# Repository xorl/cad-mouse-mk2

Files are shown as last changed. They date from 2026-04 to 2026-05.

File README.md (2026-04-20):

# CAD Mouse MK2

Watch the build video ↓

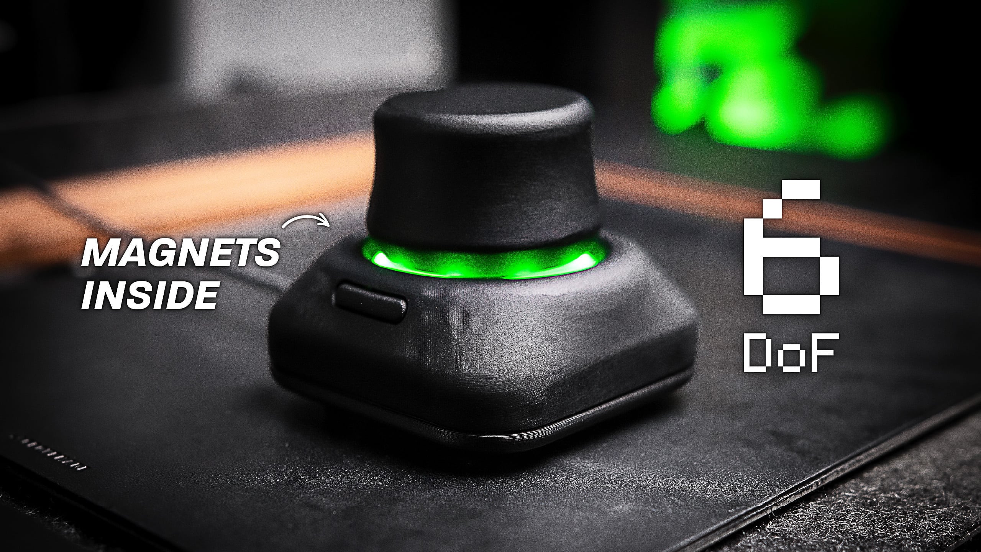
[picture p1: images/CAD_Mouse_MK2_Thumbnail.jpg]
[](https://youtu.be/62xlzGs8LXA)

This is the second iteration of my DIY CAD Mouse, rebuilt to behave like a real 6DoF controller. There are still some motion processing issues, but it's much better than the previous version. It uses a custom PCB with three magnetic sensors, a 3D printed spring, and a redesigned enclosure that is smaller and easier to build.

  Build instructions → [Instructables](https://www.instructables.com/CAD-Mouse-MK2-a-6DoF-Space-Mouse-Using-Magnets)

<sub>⚠️ There have been several comments raising concerns about the longevity of the PETG spring. If it does not last as expected, a revision of the knob design will be needed.</sub>

[][cc-by-nc-sa]

[][cc-by-nc-sa]

[cc-by-nc-sa]: http://creativecommons.org/licenses/by-nc-sa/4.0/
[cc-by-nc-sa-image]: https://licensebuttons.net/l/by-nc-sa/4.0/88x31.png
[cc-by-nc-sa-shield]: https://img.shields.io/badge/License-CC%20BY--NC--SA%204.0-lightgrey.svg

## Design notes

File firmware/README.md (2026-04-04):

You can customize several variables to tune gains, smoothing, and deadzones for all six axes.
Most of these settings are defined in [`Config.h`](include/Config.h) and are the main place to adjust the overall feel of the device.

```cpp
// Gains and sign fixes
const float GAIN_T[3] = {28.0, 28.0, 24.0};
const float GAIN_R[3] = {18.0, 18.0, 20.0};
const int SIGN_AXIS[6] = {-1, +1, -1, +1, +1, +1};

// Dead zones
const float DEAD_T = 16.0;
const float DEAD_R = 20.0;

// Smoothing
const float SMOOTH_TAU_S = 0.08;
```

⚠️ Refer to the video at [6:23](https://youtu.be/62xlzGs8LXA?si=ld2shDCaTxOLIGB8&t=383) for a demo of driver support. Related settings can be found commented in[`platformio.ini`](../platformio.ini).

⚠️ As mentioned in the video, the motion processing still needs work and may eventually be replaced entirely. This is beyond me for now, so contributions and improvements are welcome.

There is bleed between the axis due to the way each of them is calculated independently. This implementation also assumes the readings from the sensors are linear, which is not true.

If you want to experiment with different motion processing approaches, you can modify the [`MotionController`](src/controllers/MotionController.cpp). The current implementation is as follows:

**Sensor layout:**
- `mag1` = bottom
- `mag2` = top left
- `mag3` = top right

```
Tx = (mag1x + mag2x + mag3x) / 3
Ty = (mag1y + mag2y + mag3y) / 3
Tz = (mag1z + mag2z + mag3z) / 3

Rx = sqrt(3) * (mag2z + mag3z - 2 * mag1z) / 3
Ry = mag3z - mag2z
Rz = sum_i (posXi * magYi - posYi * magXi)
```
- `Tx`, `Ty`, `Tz`: average of all three sensors
- `Ry`: left-right z difference across the top edge
- `Rx`: top pair versus bottom, scaled for the triangle geometry
- `Rz`: twist estimate from the x/y sensor positions

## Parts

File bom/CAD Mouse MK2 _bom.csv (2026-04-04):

Qty | Part | Link
1 | Seeed Studio XIAO RP2040 | https://geni.us/9SqAMi
1 | Assembled Sensor Board with MCU Adapter | https://bit.ly/48rovz3
16 | M3 x 4 Heat-Set Inserts | https://geni.us/s0GG2
10 | M3 x 16 Hexagon Socket Head Cap Screw | https://geni.us/ncMxqyo
5 | M3 x 12 Hexagon Socket Head Cap Screw | https://geni.us/ncMxqyo
1 | M2 x 4 Hexagon Socket Head Cap Screw | https://geni.us/ncMxqyo
6 | 6mm x 3mm Neodymium Magnets | https://geni.us/JU58
4 | Rubber Bumper Feet | https://geni.us/vBw7v

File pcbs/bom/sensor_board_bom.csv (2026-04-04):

Reference Designators | Quantity | Description | Package | Value | Digikey
C1, C2 | 2 | 1 µF ±20% 10V Ceramic Capacitor X7R 1206 (3216 Metric) | CAPC3216X135 | 1uF | 4713-GMC31X7R105M10NTCT-ND
C3, C4, C5, C6, C7, C8, C9, C10, C11, C12, C13, C14, C15, C16, C17 | 15 | 0.1 µF ±20% 16V Ceramic Capacitor X7R 0805 (2012 Metric) | CAPC2012X110 | 100nF | 399-C0805C104K5RACTUCT-ND
C18 | 1 | 22 µF ±20% 25V Ceramic Capacitor X5R 1206 (3216 Metric) | CAPC3216X135 | 22uF | 587-3246-1-ND
D1, D2, D3, D4, D5, D6, D7, D8 | 8 | Addressable Lighting - LED Red, Green, Blue (RGB) 4.00mm L x 2.00mm W | LED_SK6812_SIDE-A | SK6812_SIDE-A | 3147-T4203GRB-12C-61013TU1930CT-ND
J1, J2 | 2 | 6 Position Header Connector 0.079" (2.00mm) Through Hole Gold | CONN3X2_NPPN032AFCN-RC_SUL | NPPN032AFCN-RCCONN3X2_NPPN032AFCN-RC_SUL | S5750-03-ND
MAG1, MAG2, MAG3 | 3 | Hall Effect Sensor Axis PG-TSOP6-6-8 (TLI493D-A2B6) | SOP95P280X110-6N-V | TLI493D-A2B6 | TLI493DA2B6HTSA1CT-ND
R1, R2 | 2 | 10 kOhms ±1% 0.125W, 1/8W Chip Resistor 0805 (2012 Metric) Automotive AEC-Q200 Thick Film | RESC2012X65 | 10K | RMCF0805FT10K0CT-ND
RN1 | 1 | 10k Ohm ±5% 62.5mW Power Per Element Isolated 4 Resistor Network/Array ±200ppm/°C 1206 (3216 Metric), Convex, Long Side Terminals | RESCAF80P320X160X60-8N | CAY16-103J4LF | CAY16-103J4LFCT-ND
S1, S2 | 2 | Tactile Switch SPST-NO Side Actuated Surface Mount, Right Angle | SW_TS32-7-35-BK-160-RA-SMT-TR | TS32-7-35-BK-160-RA-SMT-TR | 2223-TS32-7-35-BK-160-RA-SMT-TRCT-ND
U1, U2, U3, U4 | 4 | Power Switch/Driver 1:1 N/P-Channel 1A TSOT-25 | SOT95P280X100-5N | AP22816BKEWT-7 | 31-AP22816AKEWT-7CT-ND
U5 | 1 | Buffer, Non-Inverting 1 Element 1 Bit per Element 3-State Output SOT-23-5 | SOT95P280X145-5N | SN74AHCT1G125DBVR | 296-4708-1-ND
H1, H2 | 2 | Connector Header Through Hole 6 position 0.079" (2.00mm) | CONN3X2_NRPN032PAEN | NRPN032PAEN-RC | S5801-03-ND

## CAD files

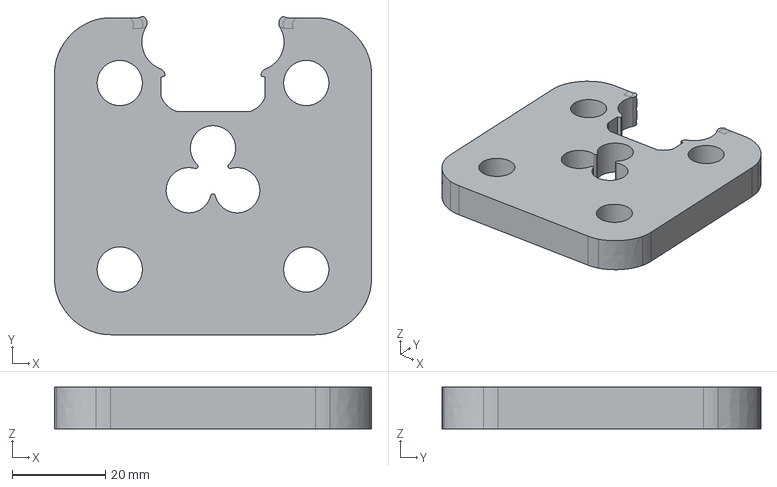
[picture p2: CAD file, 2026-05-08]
enclosure/step/void-fill.step
68.0 x 68.3 x 9.00 mm

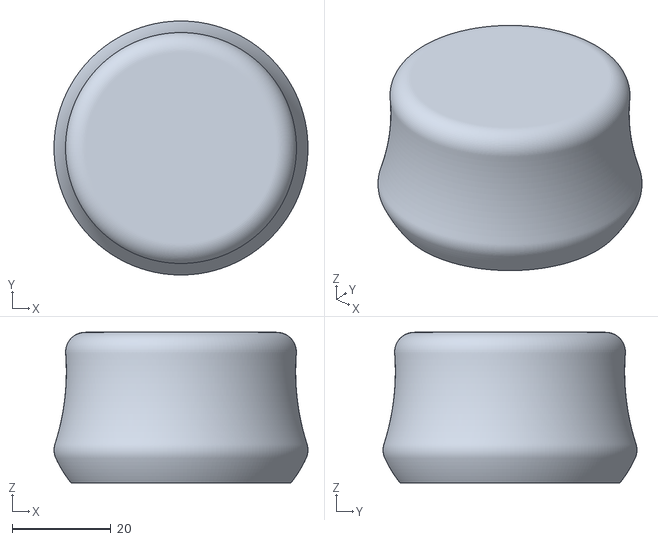
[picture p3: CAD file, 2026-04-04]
enclosure/stl/knob.stl
51.5 x 51.5 x 30.5

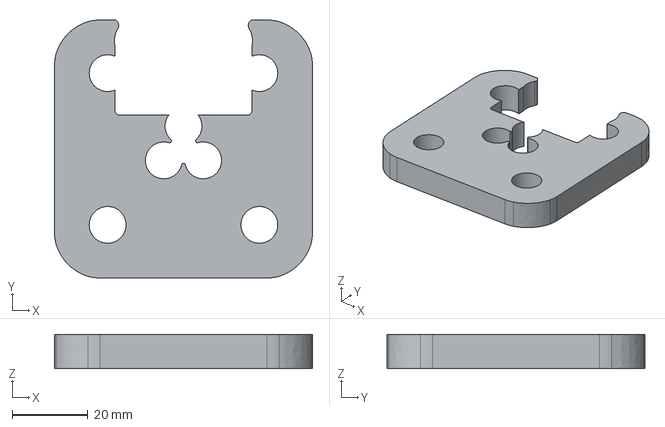
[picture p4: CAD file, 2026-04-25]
enclosure/step/Weight-for-Cad-Mouse.step
68.0 x 68.0 x 9.00 mm

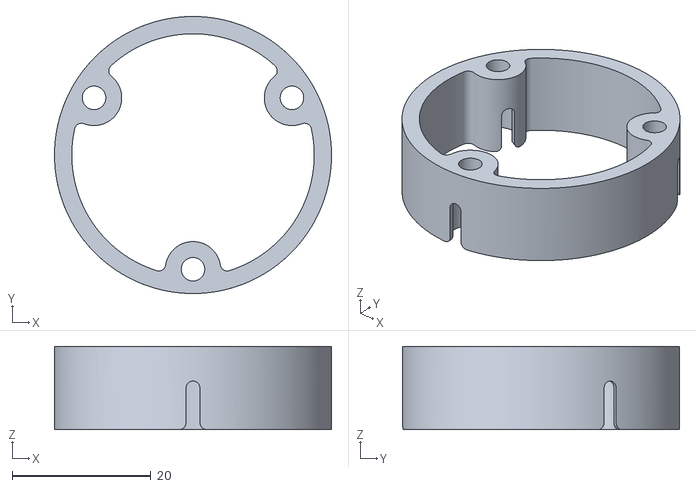
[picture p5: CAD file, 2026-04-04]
enclosure/stl/magnet_holder.stl
40.0 x 40.0 x 12.0

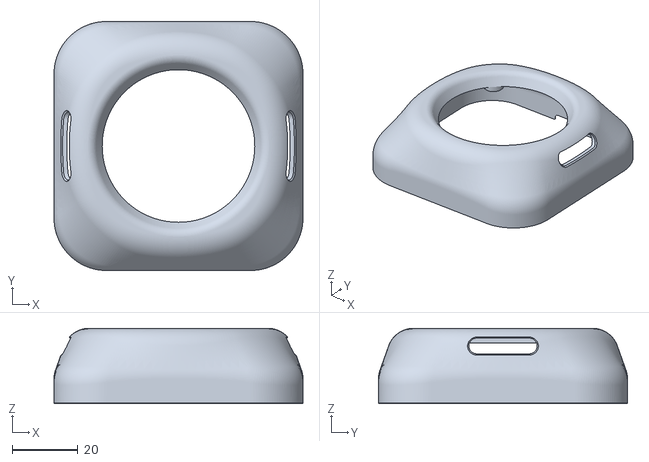
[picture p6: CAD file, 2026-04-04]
enclosure/stl/base_shell_top.stl
76.0 x 76.0 x 23.0

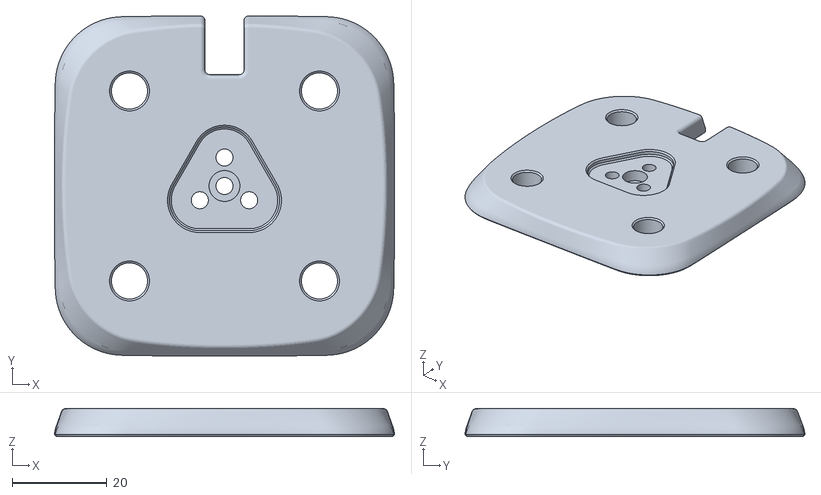
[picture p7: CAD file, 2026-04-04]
enclosure/stl/base_separator.stl
71.6 x 71.6 x 5.90

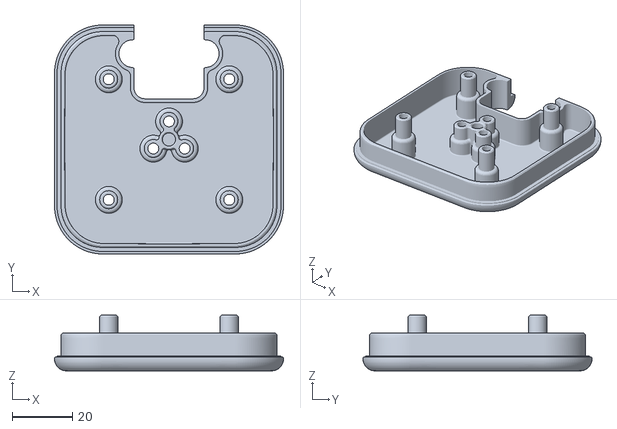
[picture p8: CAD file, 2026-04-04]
enclosure/stl/base_shell_bottom.stl
76.0 x 76.0 x 18.5

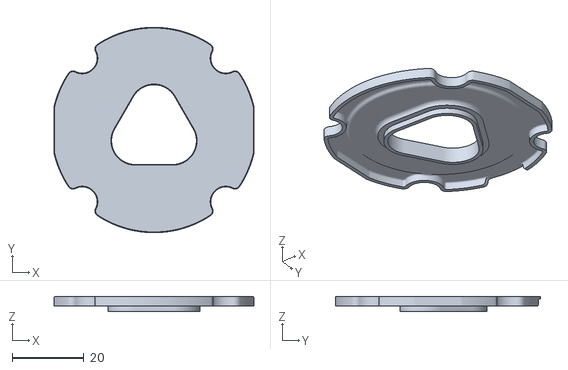
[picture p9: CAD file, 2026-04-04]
enclosure/stl/diffuser.stl
55.7 x 57.2 x 4.24

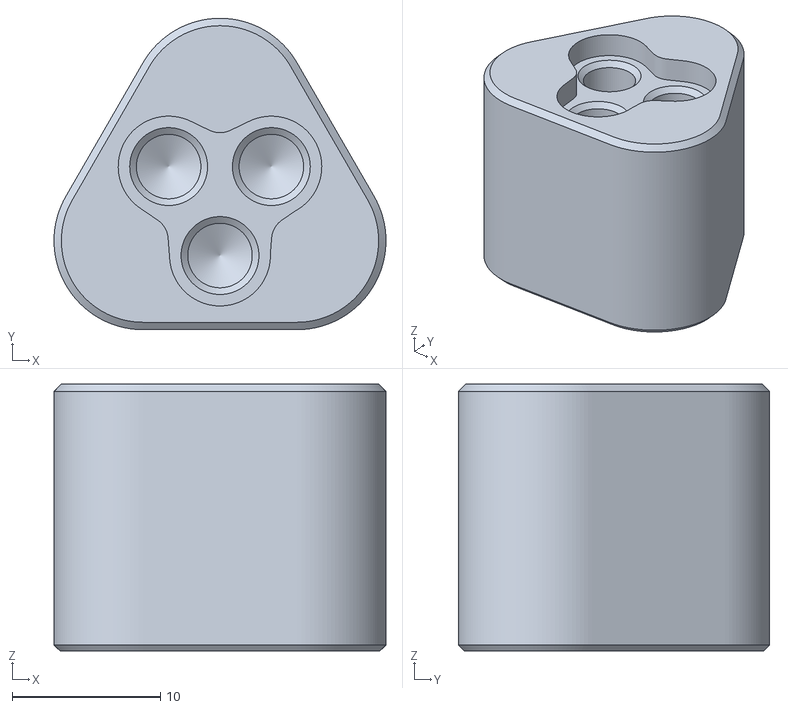
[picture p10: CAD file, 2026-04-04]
enclosure/stl/stem.stl
22.4 x 21.0 x 18.0

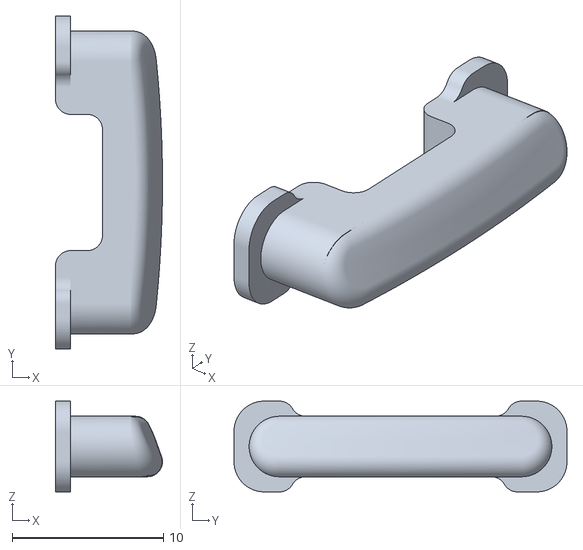
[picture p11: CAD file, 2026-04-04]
enclosure/stl/side_button.stl
7.07 x 22.0 x 6.00

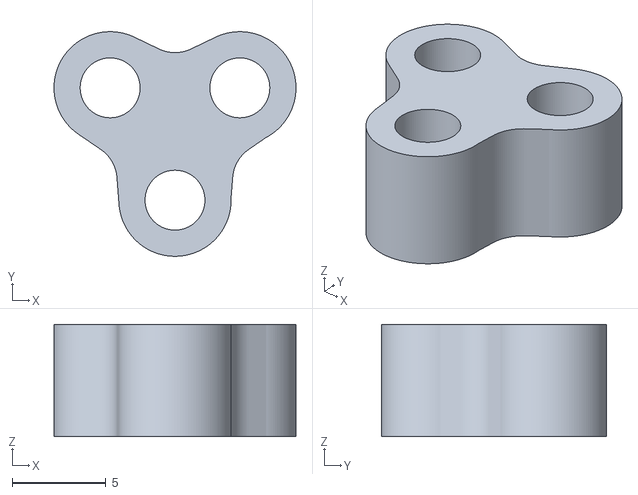
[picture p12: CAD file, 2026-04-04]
enclosure/stl/spring_spacer.stl
12.9 x 12.0 x 6.00

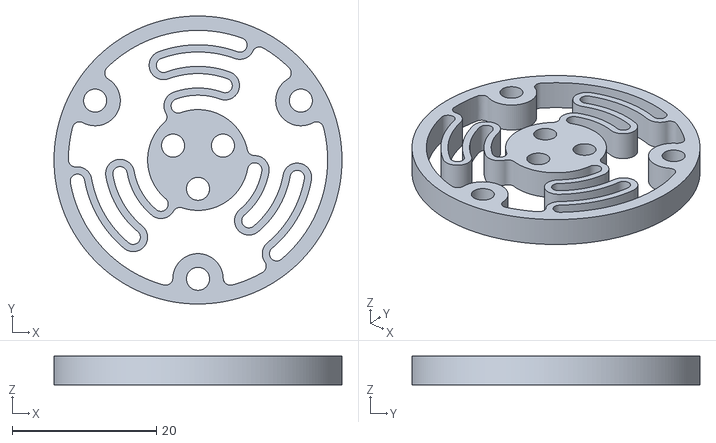
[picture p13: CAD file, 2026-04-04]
enclosure/stl/spring_1_30.stl
40.0 x 40.0 x 4.00

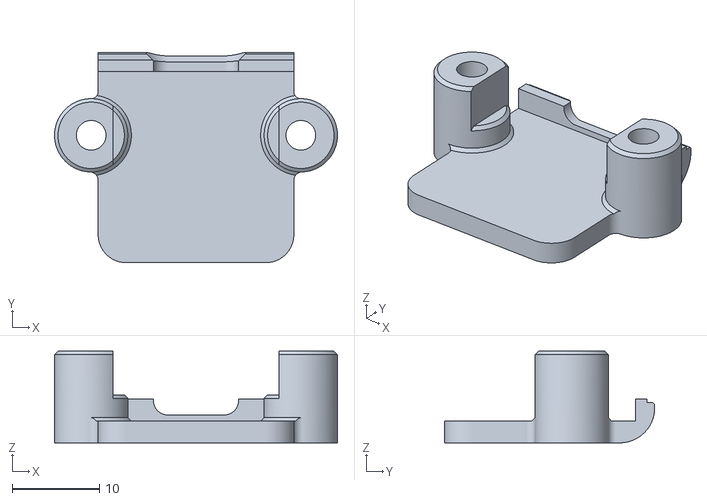
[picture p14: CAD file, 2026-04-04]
enclosure/stl/base_mcu_cover.stl
32.4 x 24.1 x 10.5

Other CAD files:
enclosure/fusion/Spring (parametric).f3d
enclosure/step/void-fill.stl

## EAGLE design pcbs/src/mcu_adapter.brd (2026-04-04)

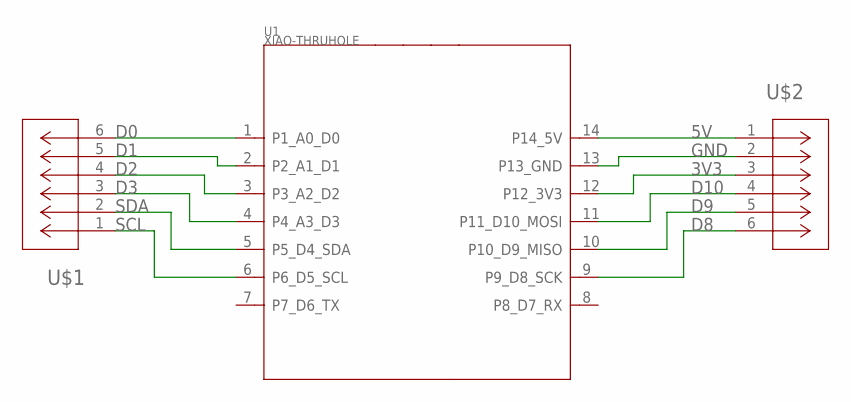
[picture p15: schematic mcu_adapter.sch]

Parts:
U1: XIAO-THRUHOLE; XIAO-GENERIC-THRUHOLE-MODULE14P-2.54-21X17.8MM
U$1, U$2: NRPN032PAEN-RC; CONN3X2_NRPN032PAEN-RC

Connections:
3V3: U1.12 (P12_3V3), U$2.3
5V: U1.14 (P14_5V), U$2.1
D0: U1.1 (P1_A0_D0), U$1.6
D1: U1.2 (P2_A1_D1), U$1.5
D2: U1.3 (P3_A2_D2), U$1.4
D3: U1.4 (P4_A3_D3), U$1.3
D8: U1.9 (P9_D8_SCK), U$2.6
D9: U1.10 (P10_D9_MISO), U$2.5
D10: U1.11 (P11_D10_MOSI), U$2.4
GND: U1.13 (P13_GND), U$2.2
SCL: U1.6 (P6_D5_SCL), U$1.1
SDA: U1.5 (P5_D4_SDA), U$1.2

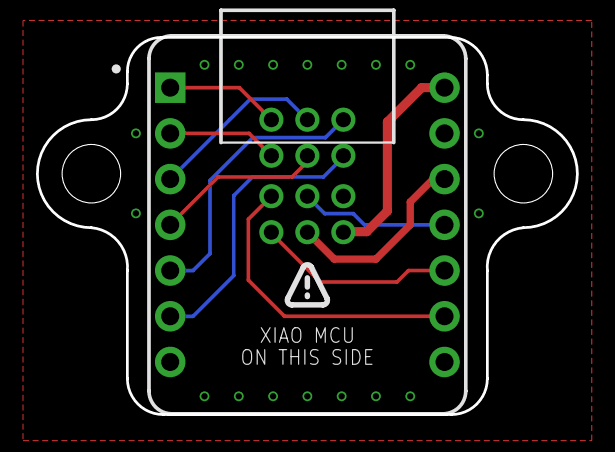
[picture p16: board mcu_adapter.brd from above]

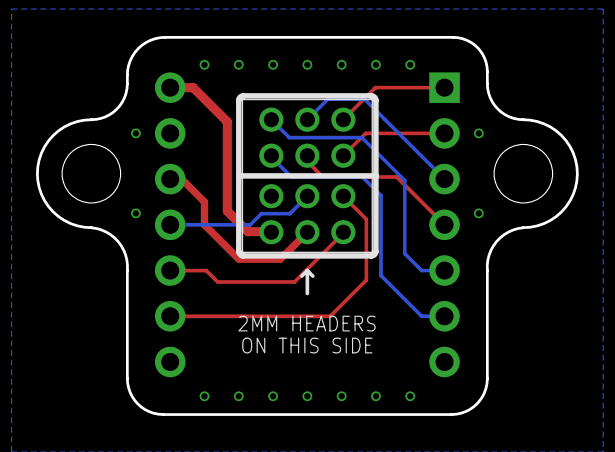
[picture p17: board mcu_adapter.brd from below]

Board: 2 copper layers, 30.0 x 21.0 mm, 3 parts (2 on the bottom side), 12 nets.

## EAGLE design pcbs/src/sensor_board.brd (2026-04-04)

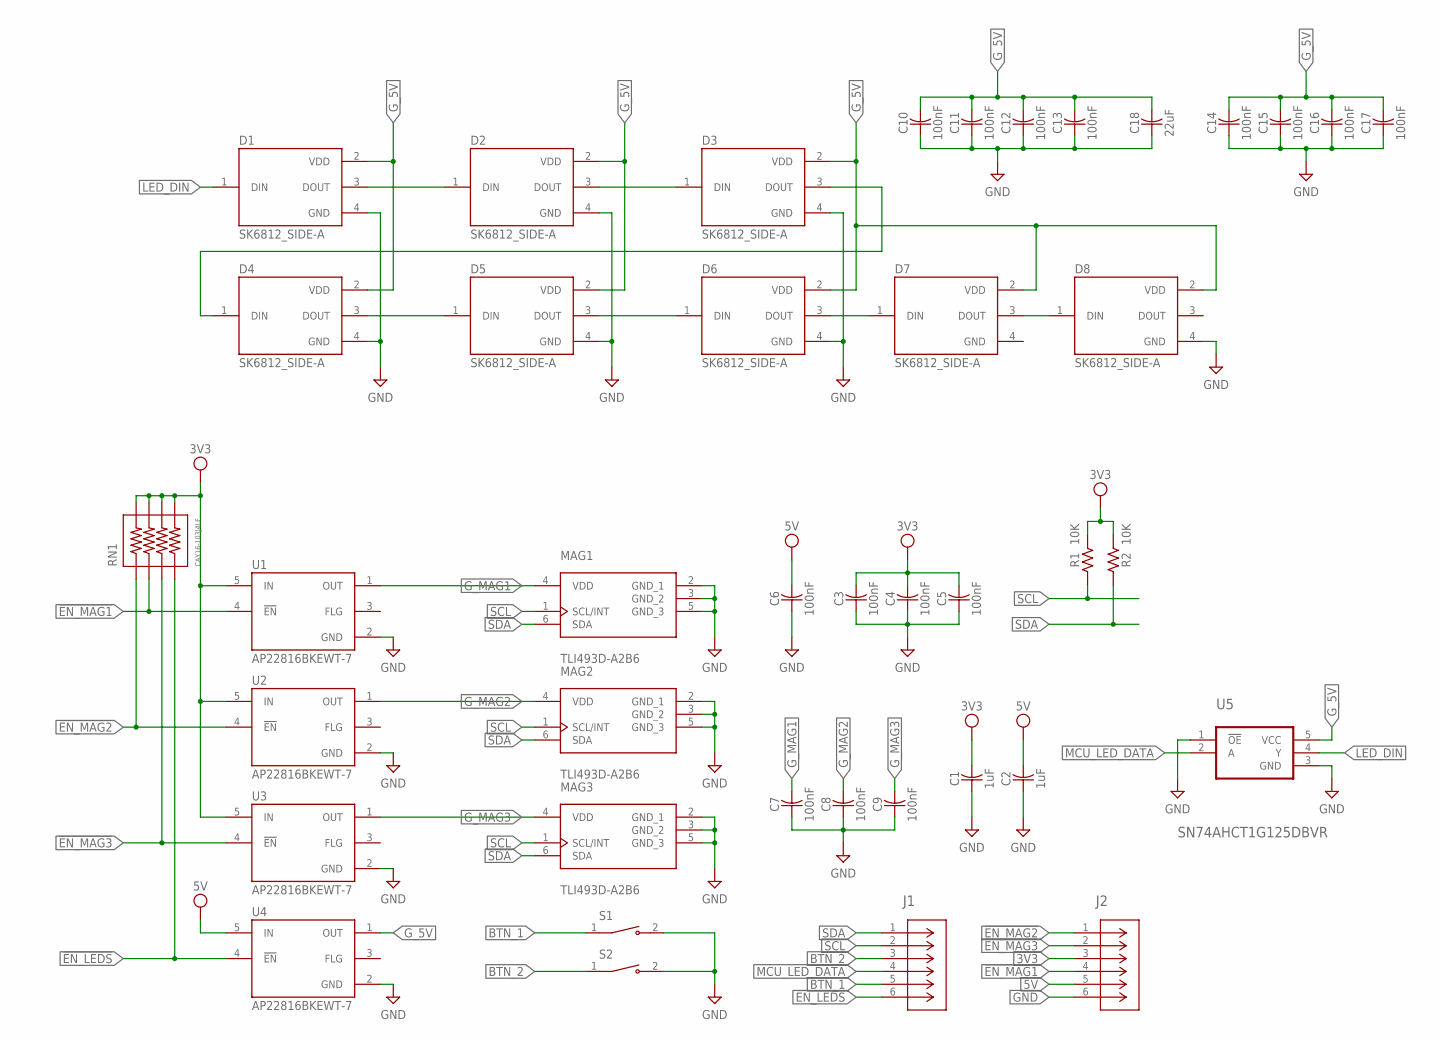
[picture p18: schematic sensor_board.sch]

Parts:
C1, C2: 1uF; CAPC3216X135
C3, C4, C5, C6, C7, C8, C9, C10, C11, C12, C13, C14, C15, C16, C17: 100nF; CAPC2012X110
C18: 22uF; CAPC3216X135
D1, D2, D3, D4, D5, D6, D7, D8: SK6812_SIDE-A; LED_SK6812_SIDE-A
J1, J2: NPPN032AFCN-RCCONN3X2_NPPN032AFCN-RC_SUL; CONN3X2_NPPN032AFCN-RC_SUL
MAG1, MAG2, MAG3: TLI493D-A2B6; SOP95P280X110-6N-V
R1, R2: 10K; RESC2012X65
RN1: CAY16-103J4LF; RESCAF80P320X160X60-8N
S1, S2: TS32-7-35-BK-160-RA-SMT-TR; SW_TS32-7-35-BK-160-RA-SMT-TR
U1, U2, U3, U4: AP22816BKEWT-7; SOT95P280X100-5N
U5: SN74AHCT1G125DBVR; SOT95P280X145-5N

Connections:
3V3: C1.2, C3.2, C4.2, C5.2, J2.3, R1.2, R2.2, RN1.5, RN1.6, RN1.7, RN1.8, U1.5 (IN), U2.5 (IN), U3.5 (IN)
5V: C2.2, C6.2, J2.5, U4.5 (IN)
!EN_LEDS: J1.6, RN1.4, U4.4 (!EN)
!EN_MAG1: J2.4, RN1.2, U1.4 (!EN)
!EN_MAG2: J2.1, RN1.1, U2.4 (!EN)
!EN_MAG3: J2.2, RN1.3, U3.4 (!EN)
BTN_1: J1.5, S1.1
BTN_2: J1.3, S2.1
GND: C1.1, C2.1, C3.1, C4.1, C5.1, C6.1, C7.1, C8.1, C9.1, C10.1, C11.1, C12.1, C13.1, C14.1, C15.1, C16.1, C17.1, C18.1, D1.4 (GND), D2.4 (GND), D3.4 (GND), D4.4 (GND), D5.4 (GND), D6.4 (GND), D7.4 (GND), D8.4 (GND), J2.6, MAG1.2 (GND_1), MAG1.3 (GND_2), MAG1.5 (GND_3), MAG2.2 (GND_1), MAG2.3 (GND_2), MAG2.5 (GND_3), MAG3.2 (GND_1), MAG3.3 (GND_2), MAG3.5 (GND_3), S1.2, S2.2, U1.2 (GND), U2.2 (GND), U3.2 (GND), U4.2 (GND), U5.1 (!OE), U5.3 (GND)
G_5V: C10.2, C11.2, C12.2, C13.2, C14.2, C15.2, C16.2, C17.2, C18.2, D1.2 (VDD), D2.2 (VDD), D3.2 (VDD), D4.2 (VDD), D5.2 (VDD), D6.2 (VDD), D7.2 (VDD), D8.2 (VDD), U4.1 (OUT), U5.5 (VCC)
G_MAG1: C7.2, MAG1.4 (VDD), U1.1 (OUT)
G_MAG2: C8.2, MAG2.4 (VDD), U2.1 (OUT)
G_MAG3: C9.2, MAG3.4 (VDD), U3.1 (OUT)
LED_DIN: D1.1 (DIN), U5.4 (Y)
MCU_LED_DATA: J1.4, U5.2 (A)
unnamed: D1.3 (DOUT), D2.1 (DIN)
unnamed: D2.3 (DOUT), D3.1 (DIN)
unnamed: D6.3 (DOUT), D7.1 (DIN)
unnamed: D3.3 (DOUT), D4.1 (DIN)
unnamed: D4.3 (DOUT), D5.1 (DIN)
unnamed: D5.3 (DOUT), D6.1 (DIN)
unnamed: D7.3 (DOUT), D8.1 (DIN)
SCL: J1.2, MAG1.1 (SCL/INT), MAG2.1 (SCL/INT), MAG3.1 (SCL/INT), R1.1
SDA: J1.1, MAG1.6 (SDA), MAG2.6 (SDA), MAG3.6 (SDA), R2.1

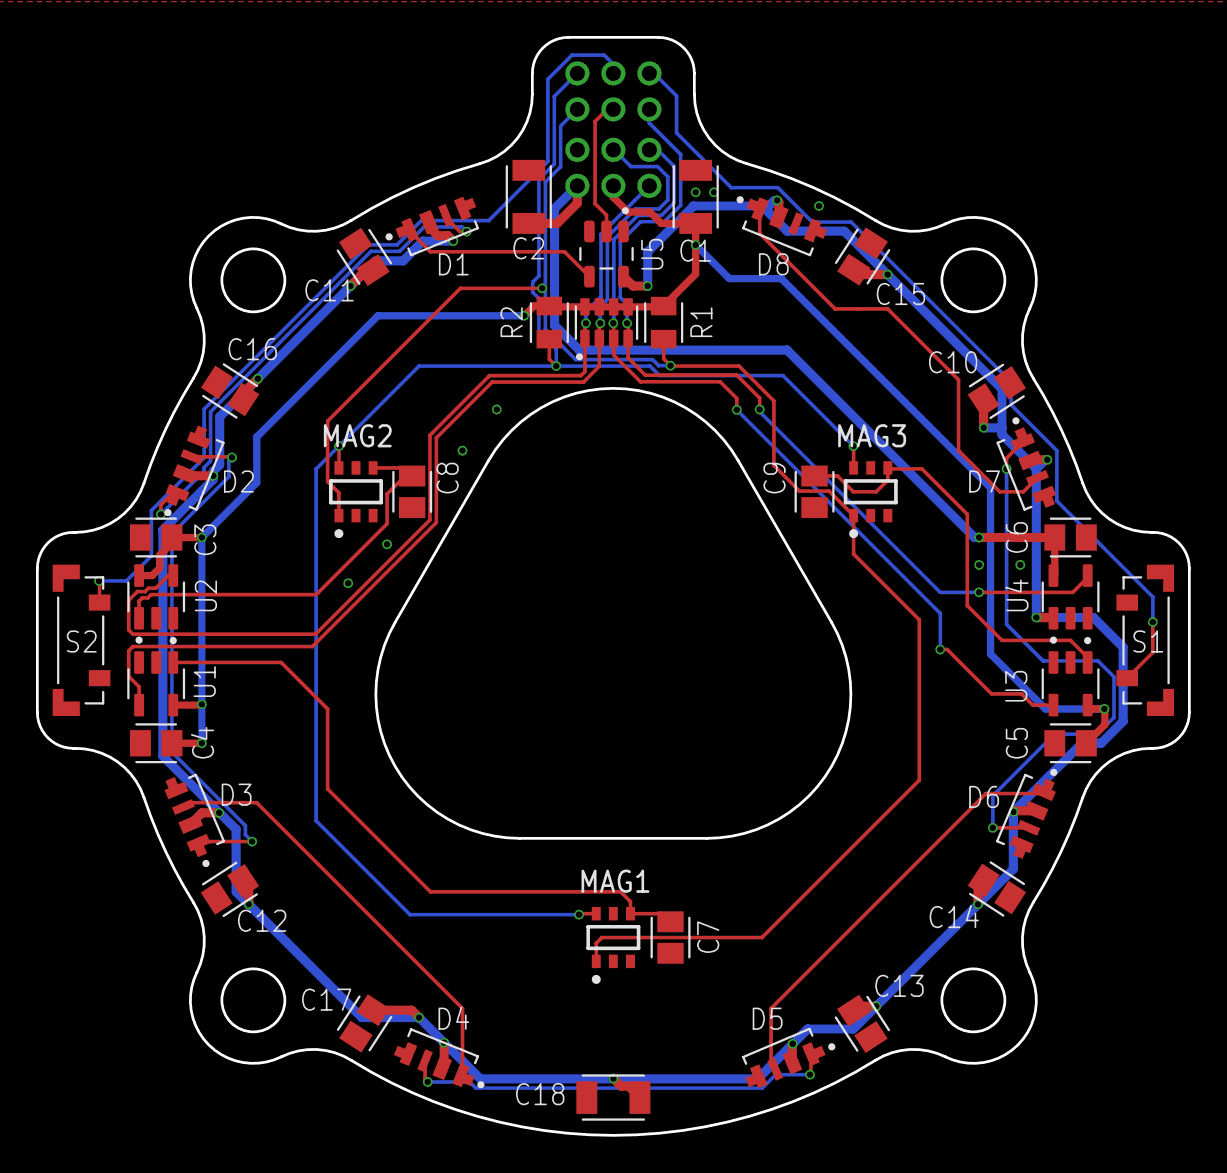
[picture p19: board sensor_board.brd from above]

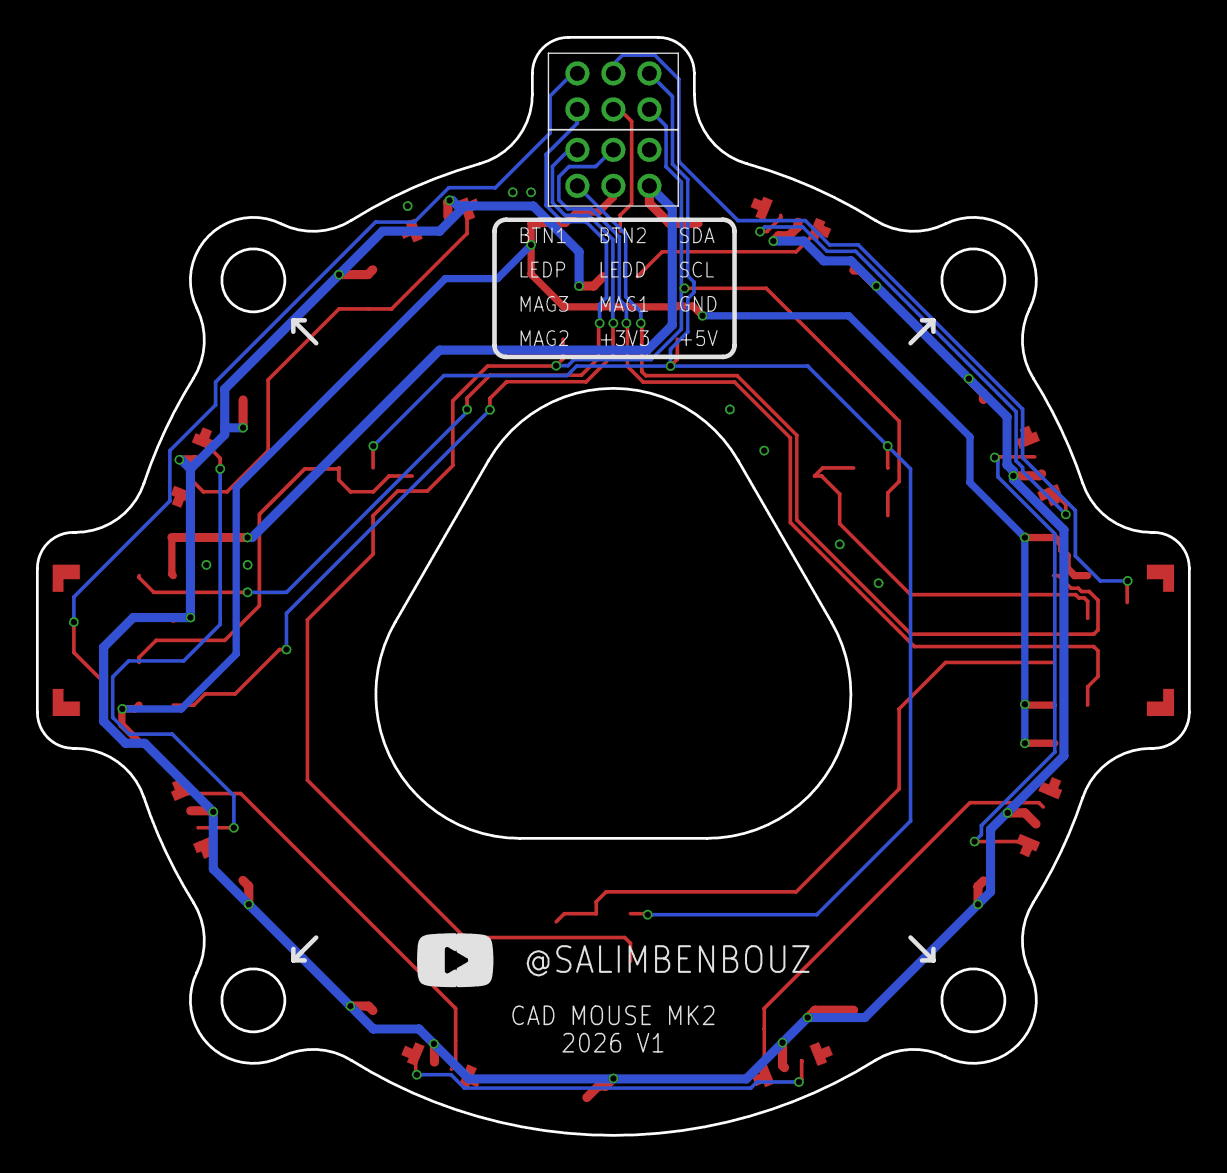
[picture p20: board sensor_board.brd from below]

Board: 2 copper layers, 64.0 x 61.0 mm, 41 parts (2 on the bottom side), 24 nets.

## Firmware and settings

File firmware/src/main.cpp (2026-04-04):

#include <Arduino.h>

#include "Config.h"
#include "Controllers.h"
#include "StateMachine.h"

InputController inputController;
LEDController ledController;
SensorController sensorController;
MotionController motionController;
HIDController hidController;
TelemetryController telemetryController;

void setup() {
  // Initialize USB HID first
  hidController.begin();

  if (Config::ENABLE_TELEMETRY) {
    Serial.begin(115200);
    delay(200);
  }

  inputController.begin();
  ledController.begin();
  sensorController.begin();
  motionController.reset();
  telemetryController.begin();

  stateMachine.changeState(&StateMachine::calibratingState);
}

void loop() {
  hidController.task();
  stateMachine.update();
}

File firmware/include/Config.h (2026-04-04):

#pragma once

#include <Arduino.h>

namespace Config {

const bool ENABLE_TELEMETRY = true;

// Hardware pins (XIAO RP2040)
const int PIN_RIGHT_BTN = D0;
const int PIN_LEFT_BTN = D2;
const int PIN_LED_DATA = D3;
const int PIN_LED_LS = D1;
const int PIN_MAG1_LS = D10;
const int PIN_MAG2_LS = D9;
const int PIN_MAG3_LS = D8;

// Samples for calibration offset
const int ZERO_SAMPLES = 200;

// Gains and sign fixes
const float GAIN_T[3] = {28.0, 28.0, 24.0};
const float GAIN_R[3] = {18.0, 18.0, 20.0};
const int SIGN_AXIS[6] = {-1, +1, -1, +1, +1, +1};

// Dead zones
const float DEAD_T = 16.0;
const float DEAD_R = 20.0;

// Smoothing
const float SMOOTH_TAU_S = 0.08;

// Final axis output range
const float AXIS_LIMIT = 350.0;

// RGB LEDs
const int LED_COUNT = 8;
const int LED_BRIGHTNESS = 40;
const unsigned long LED_IDLE_COLOR = 0x00FF00;
const unsigned long LED_CALIBRATING_COLOR = 0x0000FF;

// FSM timing
const long IDLE_SLEEP_TIMEOUT_MS = 2 * 60 * 1000;

}  // namespace Config

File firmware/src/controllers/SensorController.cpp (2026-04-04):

#include "controllers/SensorController.h"

#include "Config.h"

using namespace ifx::tlx493d;

SensorController::SensorController()
    : mag1Sensor_(Wire, TLx493D_IIC_ADDR_A0_e),
      mag2Sensor_(Wire, TLx493D_IIC_ADDR_A0_e),
      mag3Sensor_(Wire, TLx493D_IIC_ADDR_A0_e) {}

void SensorController::powerOff(int pin) { digitalWrite(pin, LOW); }

void SensorController::powerOn(int pin) {
  digitalWrite(pin, HIGH);
  delay(5);
}

void SensorController::begin() {

  pinMode(Config::PIN_MAG1_LS, OUTPUT);
  pinMode(Config::PIN_MAG2_LS, OUTPUT);
  pinMode(Config::PIN_MAG3_LS, OUTPUT);

  // All three rails are pulled high in hardware, so force them all off first
  // before bringing sensors up one-by-one for address assignment.

  powerOff(Config::PIN_MAG1_LS);
  powerOff(Config::PIN_MAG2_LS);
  powerOff(Config::PIN_MAG3_LS);
  delay(5);

  Wire.begin();
  Wire.setClock(400000);

  powerOn(Config::PIN_MAG1_LS);
  mag1Sensor_.begin(true, false, false, true);
  mag1Sensor_.setIICAddress(TLx493D_IIC_ADDR_A2_e);
  mag1Sensor_.setSensitivity(TLx493D_EXTRA_SHORT_RANGE_e);
  delay(10);

  powerOn(Config::PIN_MAG2_LS);
  mag2Sensor_.begin(true, false, false, true);
  mag2Sensor_.setIICAddress(TLx493D_IIC_ADDR_A1_e);
  mag2Sensor_.setSensitivity(TLx493D_EXTRA_SHORT_RANGE_e);
  delay(10);

  powerOn(Config::PIN_MAG3_LS);
  mag3Sensor_.begin(true, false, false, true);
  mag3Sensor_.setSensitivity(TLx493D_EXTRA_SHORT_RANGE_e);
  delay(10);
}

void SensorController::readRaw(float out[9]) {
  double mag1x = 0, mag1y = 0, mag1z = 0, temp1 = 0;
  double mag2x = 0, mag2y = 0, mag2z = 0, temp2 = 0;
  double mag3x = 0, mag3y = 0, mag3z = 0, temp3 = 0;

  mag1Sensor_.getMagneticFieldAndTemperature(&mag1x, &mag1y, &mag1z, &temp1);
  mag2Sensor_.getMagneticFieldAndTemperature(&mag2x, &mag2y, &mag2z, &temp2);
  mag3Sensor_.getMagneticFieldAndTemperature(&mag3x, &mag3y, &mag3z, &temp3);

  // MAG1 = bottom, MAG2 = top left, MAG3 = top right.
  out[0] = mag1x;
  out[1] = mag1y;
  out[2] = mag1z;
  out[3] = mag2x;
  out[4] = mag2y;
  out[5] = mag2z;
  out[6] = mag3x;
  out[7] = mag3y;
  out[8] = mag3z;
}

void SensorController::beginCalibration() {
  calibrationActive_ = true;
  calibrationDone_ = false;
  calibrationSamples_ = 0;
  lastCalibrationSampleMs_ = 0;
  for (int i = 0; i < 9; i++) {
    calibrationSum_[i] = 0.0;
  }
}

void SensorController::updateCalibration() {
  if (!calibrationActive_) {
    return;
  }

  const unsigned long now = millis();
  if (lastCalibrationSampleMs_ != 0 &&
      (now - lastCalibrationSampleMs_) < 10) {
    return;
  }
  lastCalibrationSampleMs_ = now;

  float raw[9] = {};
  readRaw(raw);

  for (int i = 0; i < 9; i++) {
    calibrationSum_[i] += raw[i];
  }

  calibrationSamples_++;
  if (calibrationSamples_ < Config::ZERO_SAMPLES) {
    return;
  }

  for (int i = 0; i < 9; i++) {
    baseline_[i] = calibrationSum_[i] / Config::ZERO_SAMPLES;
  }

  calibrationActive_ = false;
  calibrationDone_ = true;
}

bool SensorController::calibrationDone() const { return calibrationDone_; }

const float* SensorController::baseline() const { return baseline_; }

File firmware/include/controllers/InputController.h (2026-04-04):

#pragma once

#include <Arduino.h>
#include <AceButton.h>

class InputController {
 public:
  InputController();
  void begin();
  void update();

  uint16_t buttonBits() const;
  bool takeCalibrationRequest();
  bool takeActivity();

 private:
  static void handleButtonEvent(ace_button::AceButton* button, uint8_t eventType,
                                uint8_t buttonState);
  void onButtonEvent(ace_button::AceButton* button, uint8_t eventType);
  bool areBothPressed() const;

  ace_button::AceButton leftBtn_;
  ace_button::AceButton rightBtn_;

  bool calibrationRequested_ = false;
  bool hadActivity_ = false;
  unsigned long bothHeldStartMs_ = 0;
  bool calibrationHoldFired_ = false;
  bool leftPressed_ = false;
  bool rightPressed_ = false;

  static InputController* instance_;
};

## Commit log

2026-04-04 YT video upload
    [CAD Mouse MK2 _bom.csv, Spring (parametric).f3d, base_mcu_cover.stl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]
2026-04-25 Adding new weight.
    [Weight-for-Cad-Mouse.step]

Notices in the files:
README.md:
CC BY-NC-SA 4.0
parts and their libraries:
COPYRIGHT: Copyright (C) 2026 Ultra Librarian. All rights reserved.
